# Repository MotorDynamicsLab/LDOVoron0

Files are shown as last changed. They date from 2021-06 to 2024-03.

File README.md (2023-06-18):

# LDO Voron 0.2R1 Kit
This repository contains supplementary information and resources for the LDO Voron 0.2R1 Kit

## Index
- **Firmware**, contains Klipper configuration files custom to the kit.
- **Images**, images from the kit, and wiring guide, etc.
- **STLs**, printable parts and source files. 

## Preset Plates
We have gathered the most commonly parts from the Voron and LDO Repos. We saved them on as 250mm bed plates for your convenience. 

Also 
- [V02 to V02R1 Upgrade Plates]( https://github.com/MotorDynamicsLab/LDOVoron0/tree/v02r1/STLs/Preset_Print_PlatesR1/UpgradeToR1Plates)

## Legacy Versions
Users wishing to access older versions can check out the following branches:
- [V02]( https://github.com/MotorDynamicsLab/LDOVoron0/tree/v02) Branch
- [V01]( https://github.com/MotorDynamicsLab/LDOVoron0/tree/v01) Branch

## License
This repo contains both original and derivative works from the Voron project, 
which is licensed GPLv3. This repo therefore is also licensed under the terms 
of the GNU Public License, verison 3.

GPLv3 License Attributions:

https://github.com/VoronDesign/Voron-0

For more information and support:

https://vorondesign.com

https://discord.gg/voron

https://docs.ldomotors.com

https://www.ldomotion.com

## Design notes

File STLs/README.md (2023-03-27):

## Detachable Spool Holder  
This mod allows the long arm of the spool holder to be completely removed and installed in two orientations (extended or collapsed). The collapsed configuration allows easy storage and transportation.

## DIN Mounts
These are optional low profile clips that allow for your SKR Pico and Raspberry Pi Zero (with USB expander) to be mounted on DIN cleats

## Kirigami
Contains the Stealth Bed Front for mounting a neopixel to the Kirigami bed frame. Also included is a wire breakout mount for cable management.

## Mornsun PSU Cover
A safety shroud that covers up the screw terminals on the Mornsun 24V power supply. Highly recommended to prevents accidental shocks.

## Chain Anchor Skirt  
This part replaces one of the stock skirts. Instead of fastening the Z cable chain to the frame, fasten it to this skirt.

## Nameplate
Clips that can be used to mount the metal LDO kit number to your V0.2 Top hat

## Power Inlet
A slightly modified V0.2 inlet foot that holds the LDO 1.2mm AC inlet more securely.

## RPi Zero USB Expander Mount  
Those that received a Raspberry Pi Zero with the USB expander PCB can use this mount to for installation. Use two M2x10 self tapping screws and the included standoffs for fastening the Expander PCB to the mount. 

## Side Skirt with Chain Anchor
This is a V0.2 Side skirt for those who are upgrading from V0.1 and don't feel like flipping the orientation of the bed cable chain. The skirt contains a mounting point for the bed chain so it can be attached to the skirt instead of the printer frame.

## Slide-in Nut Support  
Supports the slide-in nut by lifting it up and preventing any the nut from sliding around.

## Preset Print Plates
For those who don't feel like figuring out which parts are needed to the LDO kit, we've prepared pre-arranged plates containing all the parts needed to build the kit.

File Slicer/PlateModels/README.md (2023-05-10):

# Slicer Plate Models & Textures
This folder contains models and textures that can be used in SuperSlicer or PrusaSlicer. Open Printer Settings->General->Bed Shape. 
- Under Texture, select "120_ldo_texture.svg"
- Under Model, select "Voron_120_Build_Plate.stl"

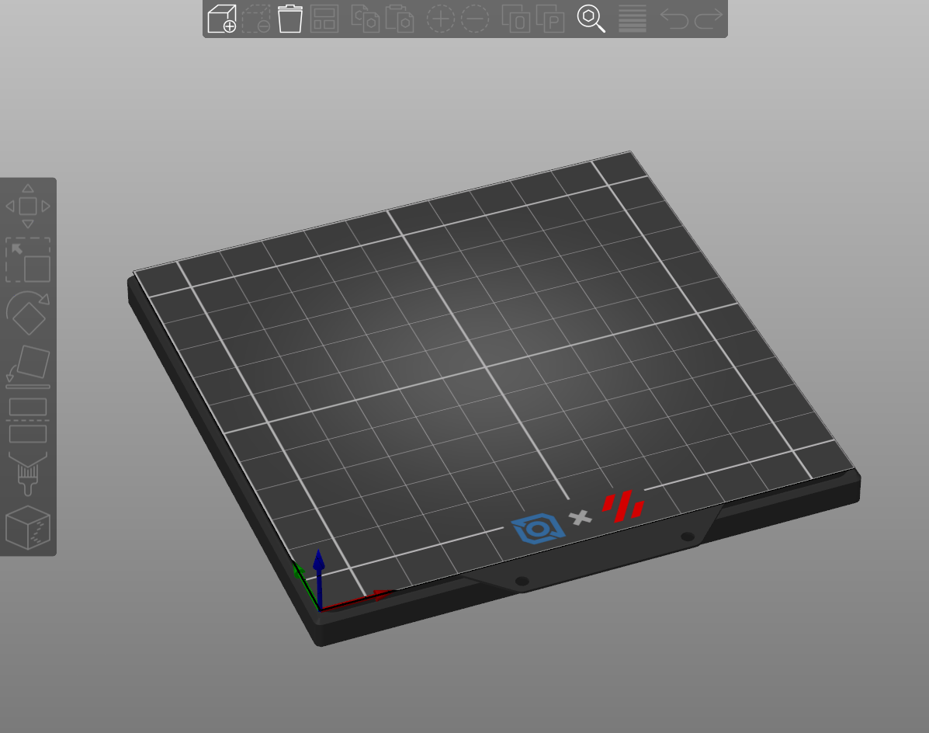
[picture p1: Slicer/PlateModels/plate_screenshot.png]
Screenshot of the LDO custom slicer plate


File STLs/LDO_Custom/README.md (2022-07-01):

# Chain Anchor Skirt
This part replaces one of the stock skirts. Instead of fastening the Z cable chain to the frame, fasten it to this skirt.

# Nameplate Middle Clip
Replaces a normal panel middle clip with a clip that can hold the metal LDO kit number nameplate.

# RPi Zero USB Expander Mount
Those that received a Raspberry Pi Zero with the USB expander PCB can use this mount to for installation. Use two M2x10 self tapping screws and the included standoffs for fastening the Expander PCB to the mount. 

# Slide-in Nut Support
Supports the slide-in nut by lifting it up and preventing any the nut from sliding around.

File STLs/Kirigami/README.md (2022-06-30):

# Kirigami Breakout Mount
This part is designed to work with the Kirigami bed mount mod, it holds 2x WAGO 221-412 terminals, and a 2x2 JST XH Splicer PCB.

# Stealth Bed Front
This is a remix of MapleLeafMakers [Stealth Bed Front Mod](https://github.com/MapleLeafMakers/Stealth_Bed_Front) which incorporates a Neopixel PCB with a JST-XH receptacle. Print the diffuser in clear filament.

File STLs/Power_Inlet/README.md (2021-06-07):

# 1.2mm Power Inlet
This part replaces the standard 1.0mm power inlet from the official [Voron repo](https://github.com/VoronDesign/Voron-0/tree/Voron0.1/STLs). The only difference is this part adapts to 1.2mm AC inlets for a more snug fit.

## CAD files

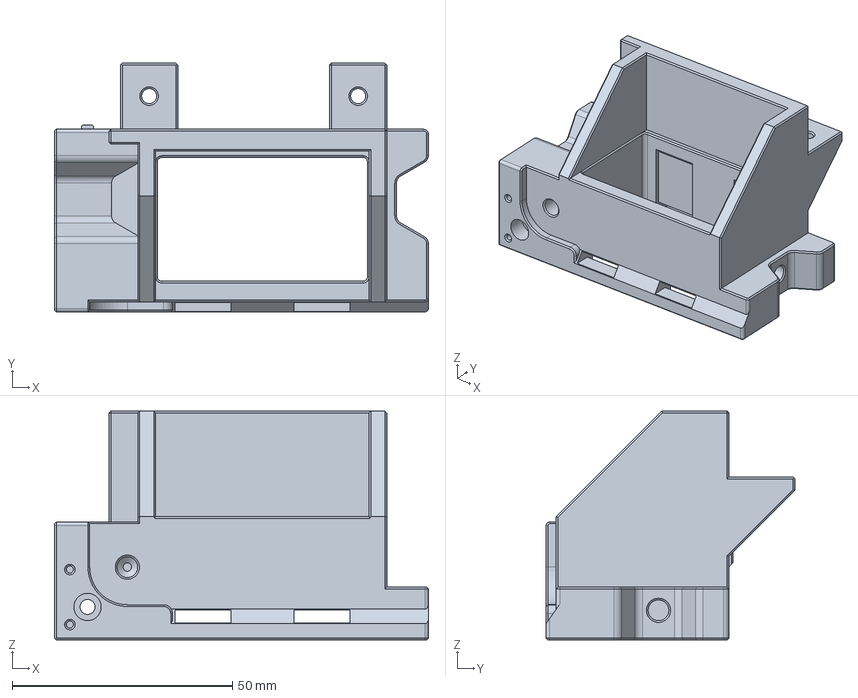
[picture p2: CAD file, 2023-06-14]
STLs/Power_Inlet/V02R1_Mains_Inlet Foot_1_2mm.step
84.9 x 56.5 x 52.0 mm

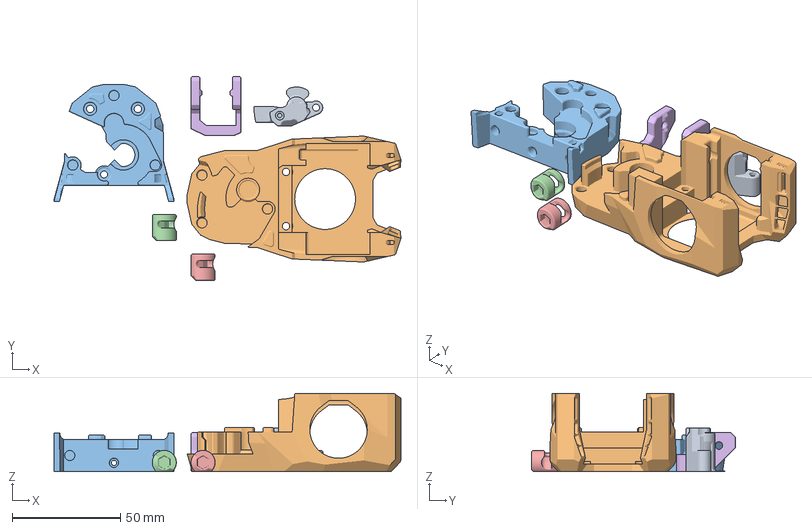
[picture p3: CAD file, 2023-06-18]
STLs/Preset_Print_PlatesR1/UpgradeToR1Plates/LDO_[a]_Main_Toolhead_PlateR1.3mf
160.0 x 93.8 x 36.1 mm
[a]_Guidler_x1.STL
[a]_MiniSB_Cowling_x1.STL
[a]_MiniSB_MidBody_x1.STL
[a]_Idler_Cam_Lock_x2.STL
[a]_Z_Endstop_Mount_x1.STL

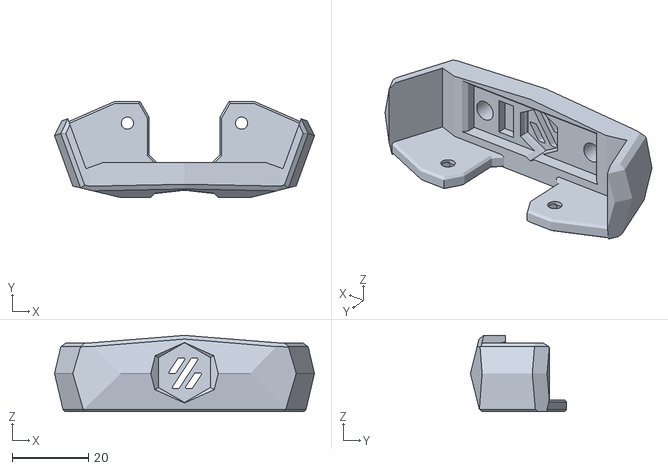
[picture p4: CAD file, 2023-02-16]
STLs/Kirigami/Stealth_Bed_Main_Body.stl
68.2 x 25.2 x 20.0

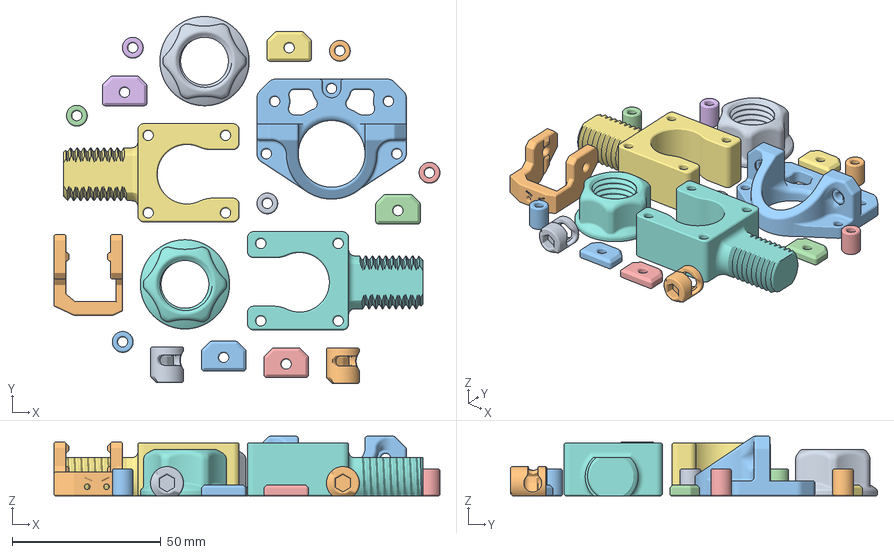
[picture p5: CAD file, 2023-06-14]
STLs/Preset_Print_PlatesR1/LDO_[a]_Main_PlateR1.3mf
129.7 x 123.3 x 20.0 mm
[a]_9mm_Spacer_x6.stl
[a]_A_Drive_Tensioner_x1.stl
[a]_B_Drive_Tensioner_x1.stl
[a]_Idler_Cam_Lock_x2.STL
[a]_Railstops_x5.stl
[a]_Tensioner_Knob_x2.stl
[a]_Z_Endstop_Mount_x1.STL
[a]_Z_Motor_Mount_x1.stl

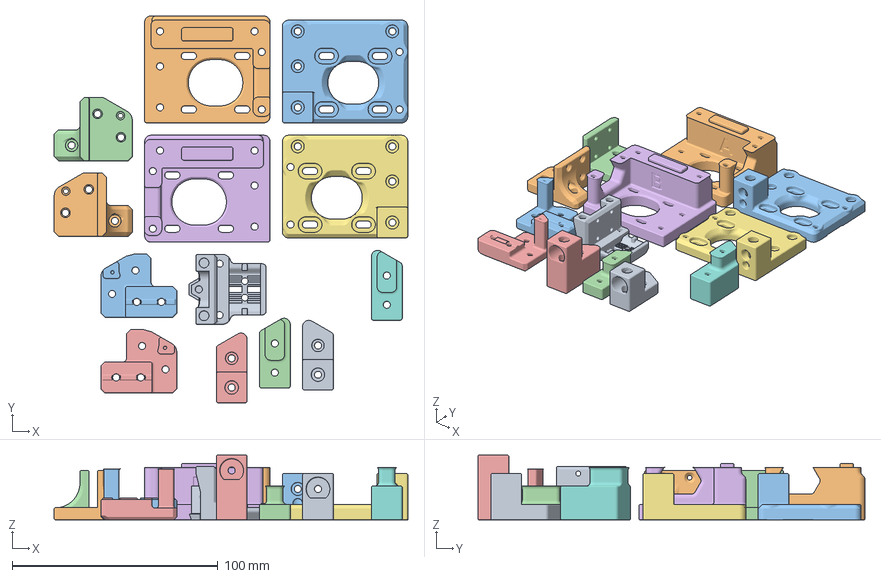
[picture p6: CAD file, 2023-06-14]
STLs/Preset_Print_PlatesR1/LDO_Main_PlateR1.3mf
172.0 x 188.3 x 31.5 mm
X_Carriage_x1.stl
A_Drive_Frame_Lower_x1.stl
A_Drive_Frame_Upper_x1.stl
A_Idler_Lower_x1.stl
A_Idler_Upper_x1.stl
B_Drive_Frame_Lower_x1.stl
B_Drive_Frame_Upper_x1.stl
B_Idler_Lower_x1.stl
B_Idler_Upper_x1.stl
XY_Joint_Left_Lower_x1.stl
XY_Joint_Left_Upper_x1.stl
XY_Joint_Right_Lower_x1.stl
XY_Joint_Right_Upper_x1.stl

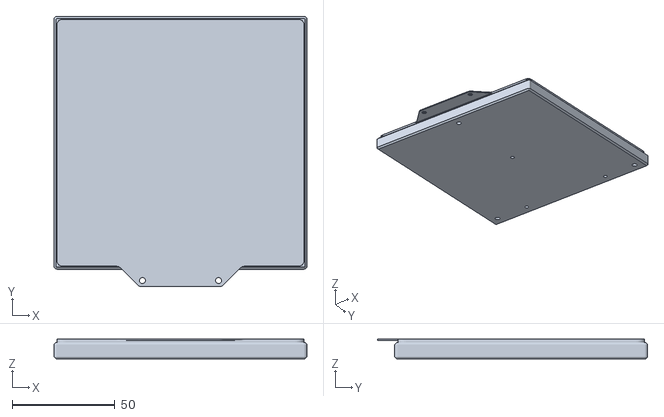
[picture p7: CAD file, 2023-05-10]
Slicer/PlateModels/Voron_120_Build_Plate.stl
123.0 x 131.5 x 9.60

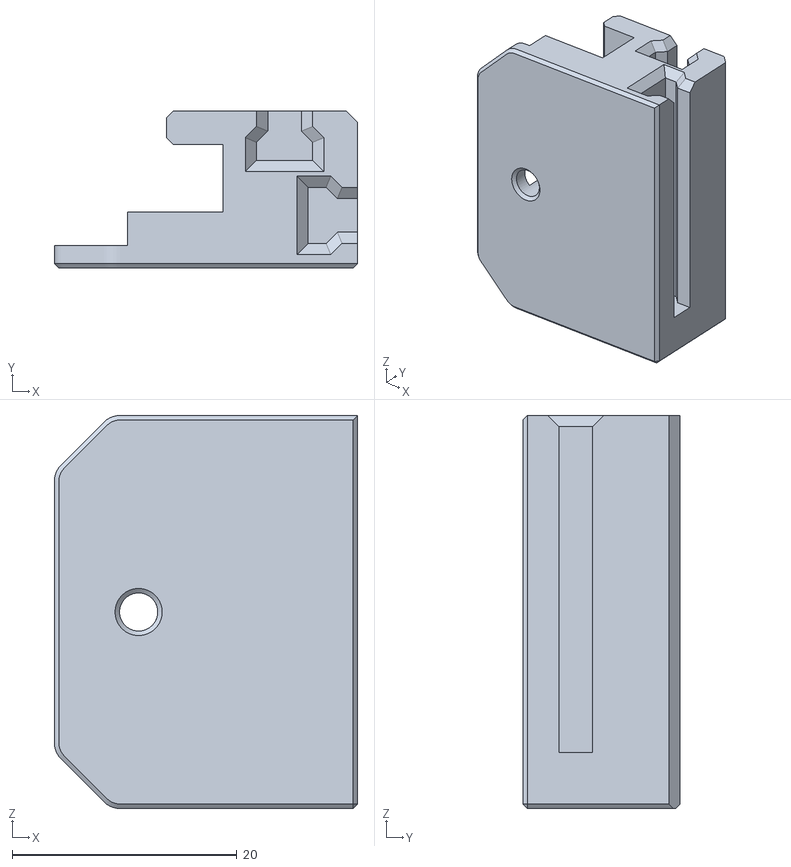
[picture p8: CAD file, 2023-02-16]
STLs/Detachable_Spool_Holder/Spool_Holder_Mount.stl
27.0 x 14.0 x 35.0

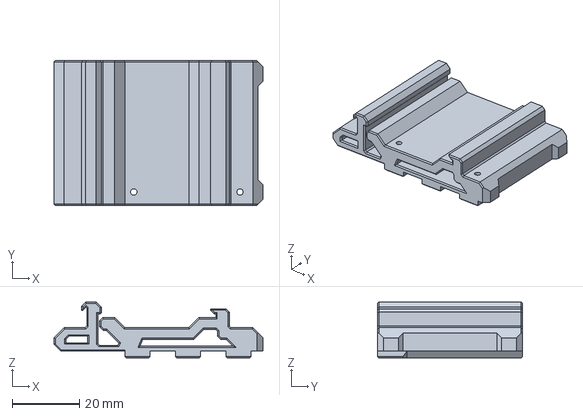
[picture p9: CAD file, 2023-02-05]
STLs/DIN_Mounts/Pi Expansion Clips.step
62.0 x 43.0 x 16.6 mm

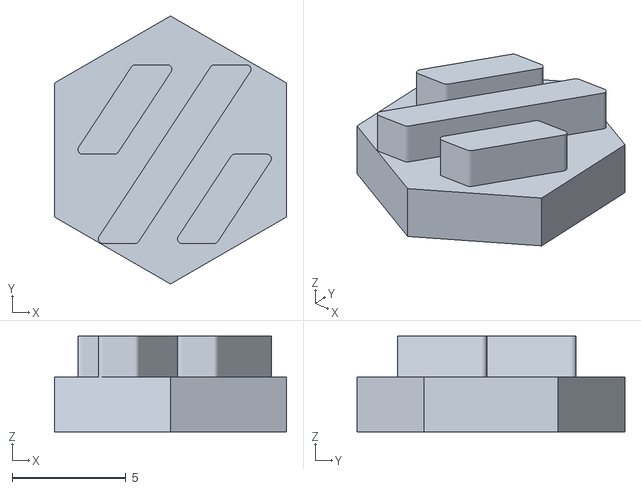
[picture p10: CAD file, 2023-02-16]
STLs/Kirigami/[c]_Stealth_Bed_Diffuser.stl
10.2 x 11.8 x 4.20

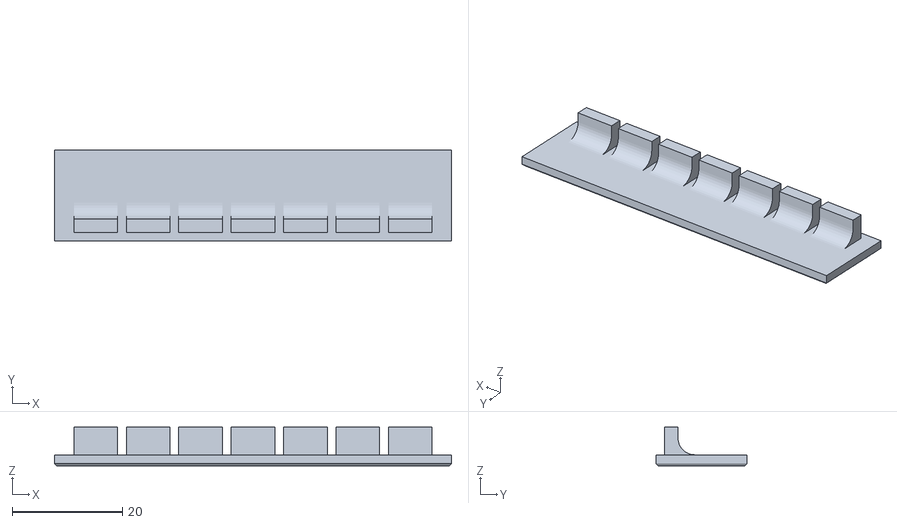
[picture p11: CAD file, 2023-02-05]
STLs/Mornsun_PSU_Cover/Mornsun_PSU_Cover.stl
72.0 x 16.5 x 7.00

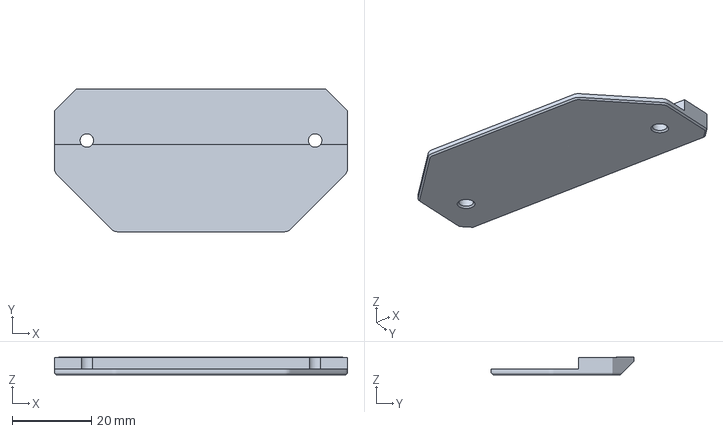
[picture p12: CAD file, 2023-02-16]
STLs/Name_Plate/Name_Plate_Top_Logo_Multi.3mf
73.8 x 35.9 x 4.42 mm

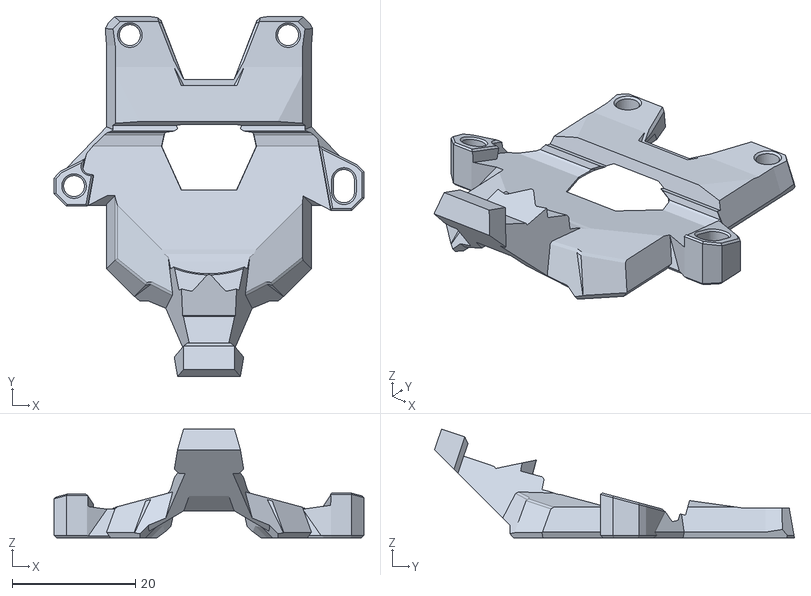
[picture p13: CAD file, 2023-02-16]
STLs/Picobilical_Toolhead/Picobilical_Strain_Relief.stl
50.3 x 58.5 x 17.7

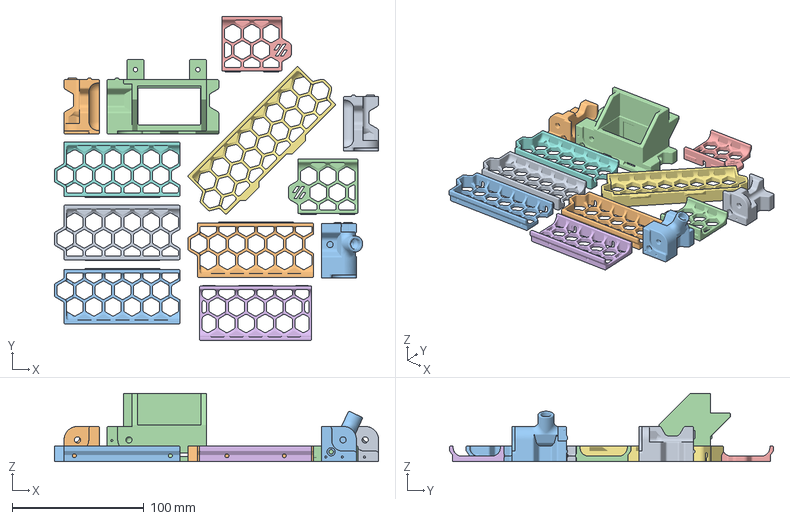
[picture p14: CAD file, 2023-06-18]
STLs/Preset_Print_PlatesR1/UpgradeToR1Plates/LDO_Skirts_PlateR1.3mf
246.6 x 246.3 x 52.0 mm
Foot_Front_Left_x1.STL
Foot_Front_Right_x1.STL
Foot_Rear_Right_FRS_x1.STL
Front_Skirt_A_x1.STL
Front_Skirt_B_x1.STL
Headless_Skirt_Insert.STL
Rear_Skirt_x1.STL
Side_Skirt_Mirror_x2.stl
Side_Skirt_x2.STL
V02R1_Mains_Inlet Foot_1_2mm.stl

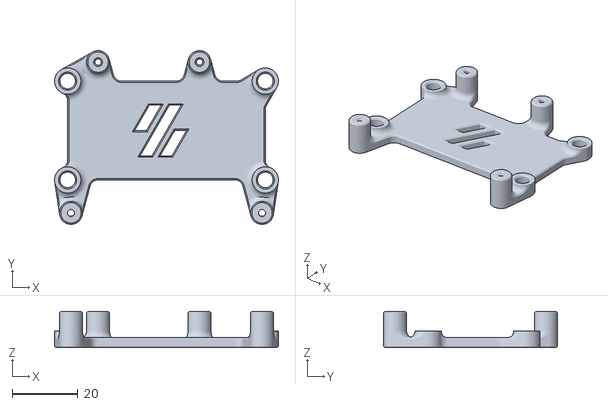
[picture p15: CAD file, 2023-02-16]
STLs/RPi_Zero_USB_Expander_Mount/RPi_Zero_USB_Expander_Mount.stl
68.0 x 52.8 x 11.0

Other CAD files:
STLs/Preset_Print_PlatesR1/LDO_[c]_Mods_KirigamiR1.3mf
STLs/Detachable_Spool_Holder/Spool_Holder.stl
STLs/DIN_Mounts/SKR Pico Mount_x2.step
STLs/Kirigami/Kirigami_LDO_Breakout_Mount.stl
STLs/DIN_Mounts/DIN Screw Cleat_x2.step
STLs/DIN_Mounts/DIN Screw Cleat_x2.stl
STLs/DIN_Mounts/Pi Expansion Clips.stl
STLs/DIN_Mounts/SKR Pico Mount_x2.stl
STLs/Detachable_Spool_Holder/V0 Detachable Spool Holder.f3d
STLs/Kirigami/Kirigami LDO Breakout Mount.f3d
STLs/Kirigami/Stealth Bed Front.f3d
STLs/Mornsun_PSU_Cover/Mornsun PSU Cover.f3d
STLs/Name_Plate/Name_Plate.stl
STLs/Name_Plate/Name_Plate_Top.stl
STLs/Name_Plate/Name_Plate_Top_Logos.stl
STLs/Picobilical_Toolhead/Picobilical Toolhead Mount V02.step
STLs/Picobilical_Toolhead/Picobilical_Strain_Relief_Extender_x2.stl
STLs/Picobilical_Toolhead/Picobilical_Strain_Relief_Spacer_A.stl
STLs/Picobilical_Toolhead/Picobilical_Strain_Relief_Spacer_B.stl
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

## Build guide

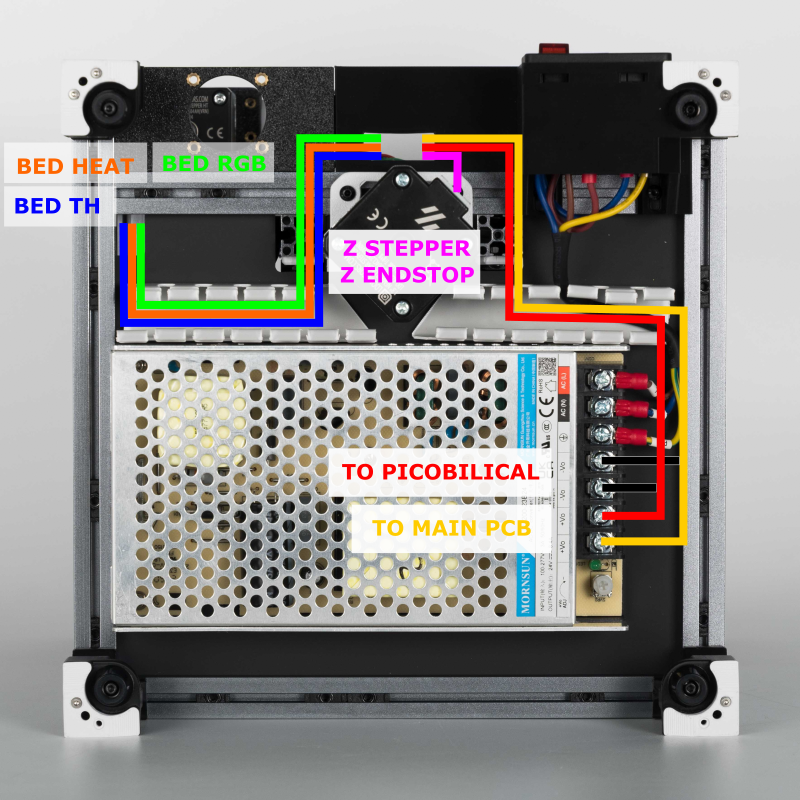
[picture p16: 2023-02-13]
Images/WiringGuide/v02/s04_mapping.png

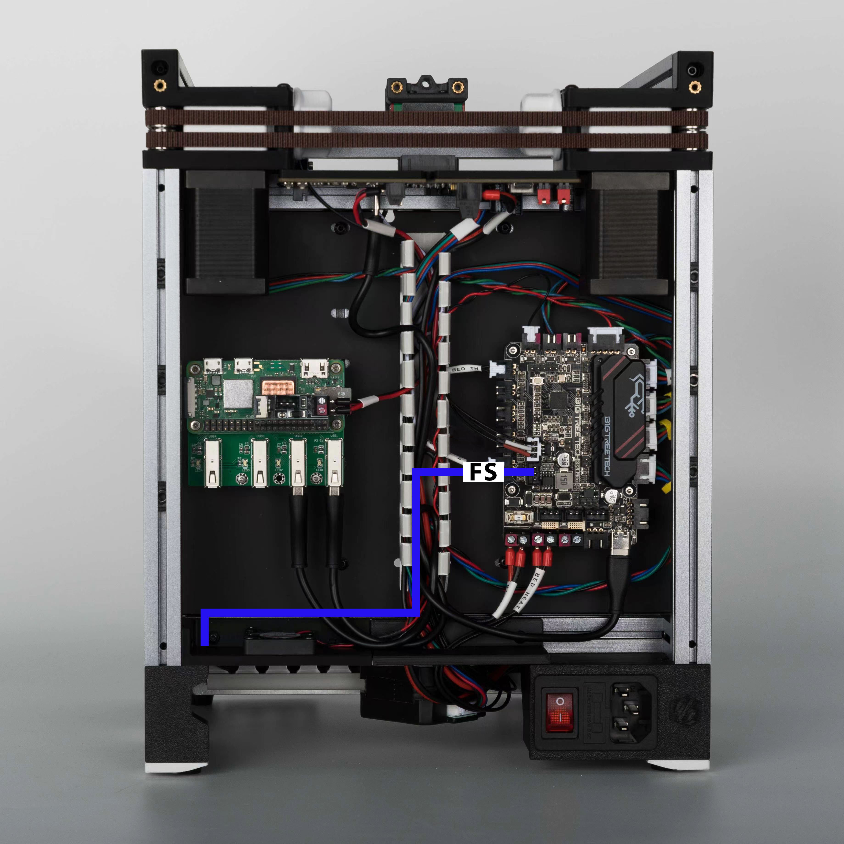
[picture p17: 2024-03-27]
Images/WiringGuide/S1/s14_mapping.jpg

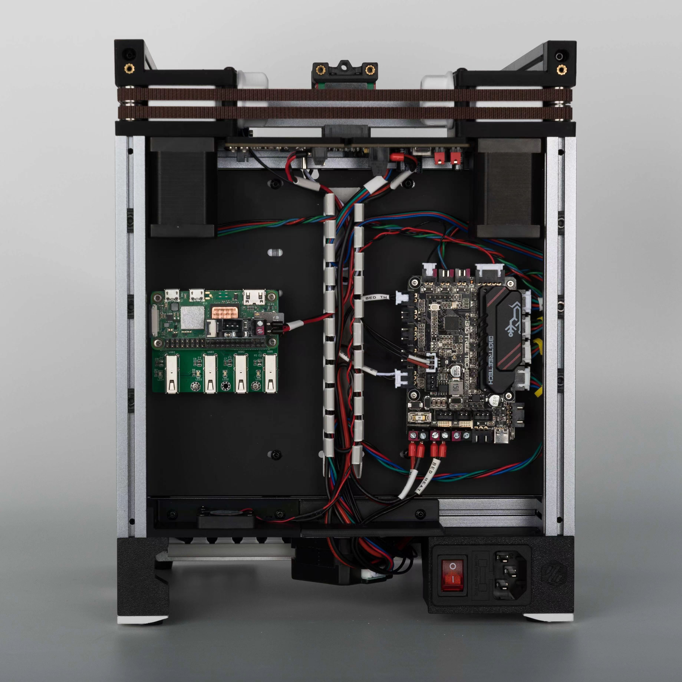
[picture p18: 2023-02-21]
Images/WiringGuide/v02/s11_pcb_fan.jpg

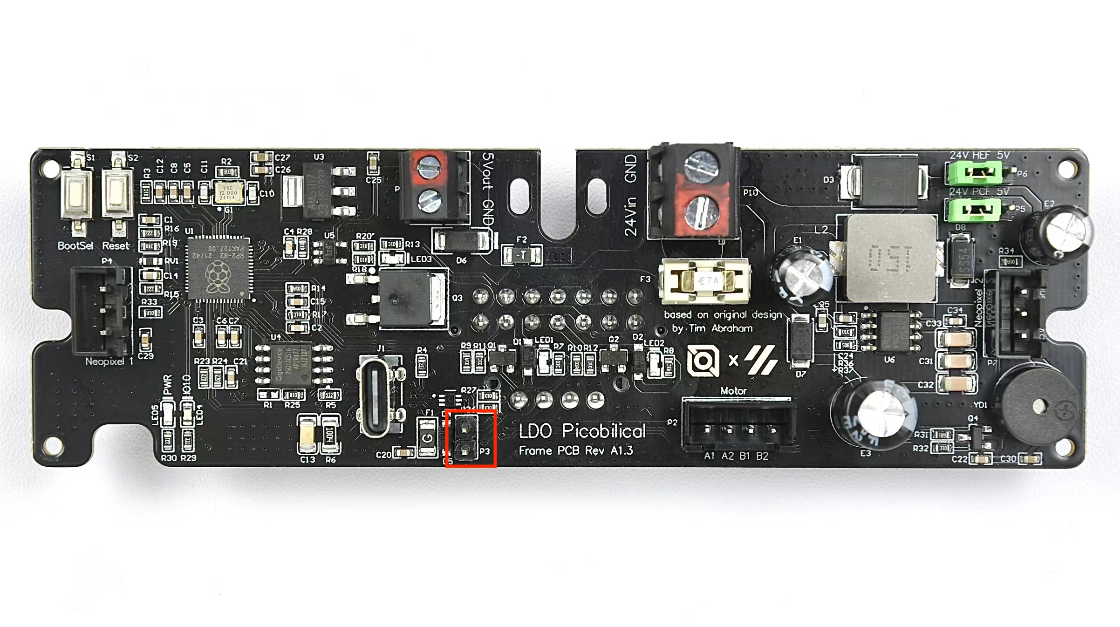
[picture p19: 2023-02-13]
Images/WiringGuide/v02/picobilical_hef_24v_usb_jumper_labelled.jpg

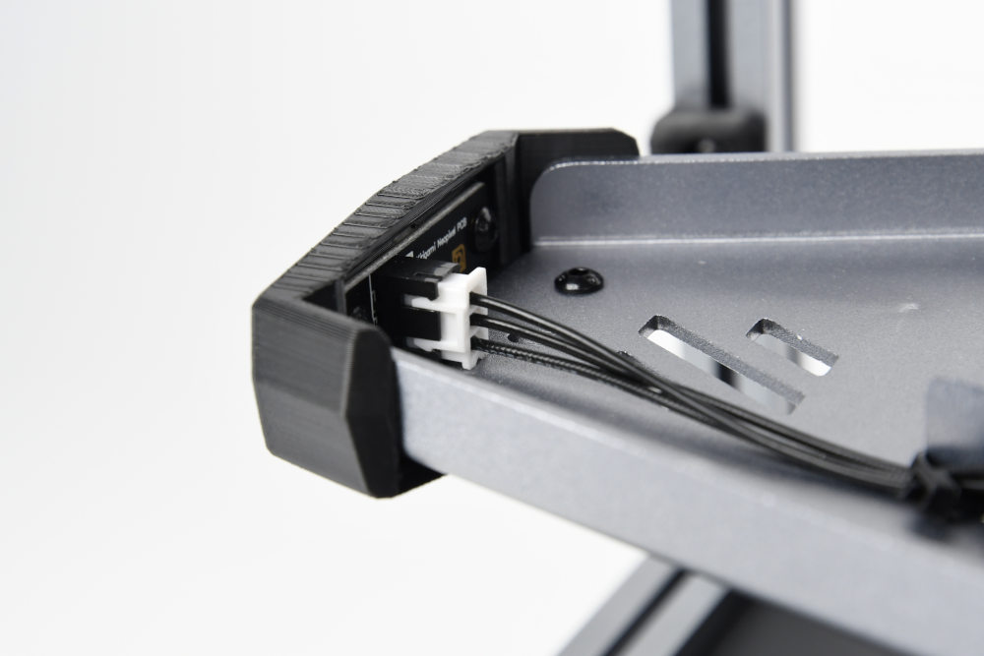
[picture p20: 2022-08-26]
Images/Kirigami/kirigami_neopixel_cable_installed.JPG

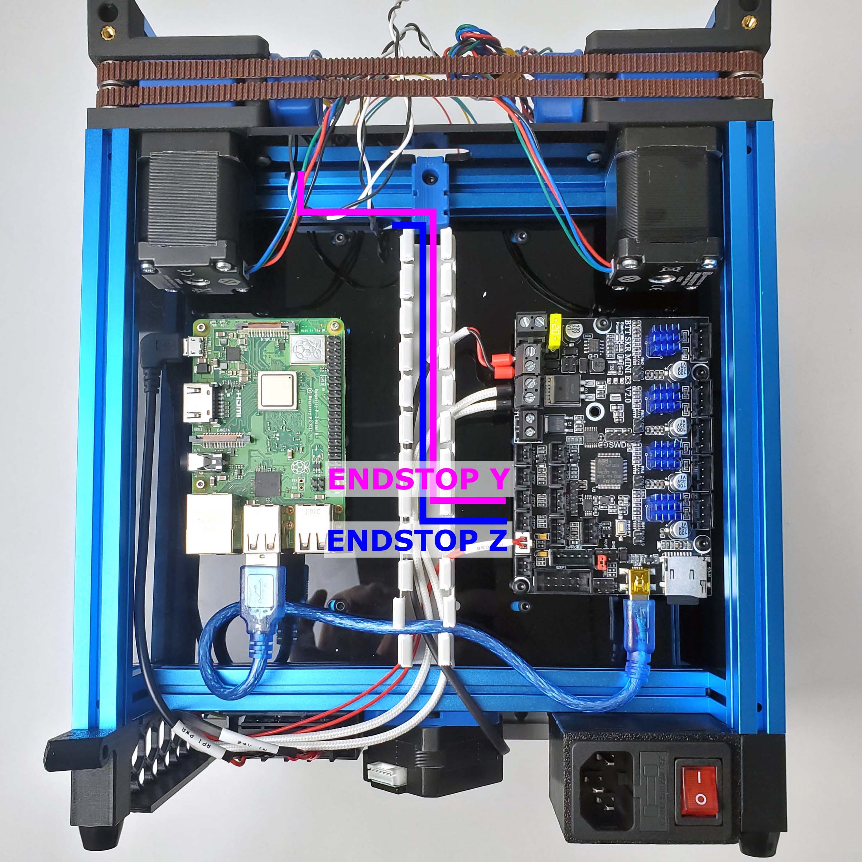
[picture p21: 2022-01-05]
Images/WiringGuide/elec2_layout.jpg

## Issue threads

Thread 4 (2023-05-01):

Picobilical toolhead spacer missing from Preset_Print_Plates

slashbeast, 2023-05-01:
The printed parts guide at https://docs.ldomotors.com/voron/voron02/printed_part_guide_rev_a mention toolhead spacer for Picobilical but the part seems to be missing in preset print plates, is it intentional?

camerony, 2023-08-29:
This was fixed.  Thanks

Closed 2023-08-29.

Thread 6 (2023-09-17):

Documentation docs.ldomotors.com/en/voron/voron02/build-faqv02

JassMan23, 2023-09-17:
The above document says:
"PAGE 143 Use M3 lock nuts with the flat side up rather the the M3 hex nut and washer. We recommend
using an M3x30 or M3x35 screw for the Kirigami bed instead of the M3x40"

However it is virtually impossible to to install a lock nut backwards without stripping the nut or the screw since the nylon lock can not be guaranteed to cut a thread which is a continuation of the actual nut thread. Because of its resilience, the thread in the nylon recovers its smoothness before you are able to reverse it, if you thread it the normal way first.

A better solution is to use 2 hex (jam)nuts so the second locks against the first.
Or providing something like this: 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

camerony, 2023-09-28:
Thanks for the feedback.  We will consider that.

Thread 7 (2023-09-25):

Power inlet needs to be resized

MrJohnson, 2023-09-25:
From the 0.2 R1 release notes:

"Skirts

We fixed the issue where 34mm Z motors didnt fit in the machine with the bottom panel installed, this involved increasing the height of the skirts/feet by 2mm
We added a simple filament runout sensor to the rear right foot"

The LDO-provided power inlet stl is now a different size than the official release and causes the printer to rock.

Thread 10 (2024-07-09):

Wrong GPIO listed for Filament Sensor 1

xanderphillips, 2024-07-09:
File has:
switch_pin: umb:gpio6

But if the wiring was done per the documentation to the E Stop on the SKR Pico board, the entry should be:
switch_pin: !gpio16

Found via the bigtreetech github for the SKR Pico board.

cneshi, 2024-07-09:
Both pins are already listed in the config for you to choose because both the SKR Pico and Picobilical have filament sensor ports. Please see line 379 - 389 in printer.cfg

Closed 2024-07-09.

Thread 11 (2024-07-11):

homing problem with z when issuing

xanderphillips, 2024-07-11:
To repro:
issue G28 X or G28 Y repeatedly without issuing a G28 Z or a home all command.

Slipperyclock, 2025-06-09:
I have had the same issue with mine.  Newly built LDO V0.2 S1, ran fine for a little while then all of a sudden this problem came up.  I had to remove the "Z20" from line 492, https://github.com/MotorDynamicsLab/LDOVoron0/blob/4c543a41f25372adbd4c650e5aab1d722c46461a/Firmware/printer.cfg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.

I am surprised no one else is having this issue its almost a year.

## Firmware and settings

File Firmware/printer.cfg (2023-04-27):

## LDO V0.2 Printer Configuration
## NOTE: The order of the [include] are IMPORTANT


#####################################################################
#   User Interface Software
#####################################################################
## Uncomment depending on your software choice either Fluidd or Mainsail
# [include fluidd.cfg]
# [include mainsail.cfg]

[mcu]
#####################################################################
# Obtain definition by "ls -l /dev/serial/by-id/"
#####################################################################
serial: /dev/serial/by-id/{REPLACE WITH YOUR SERIAL}
restart_method: command
##--------------------------------------------------------------------

[mcu umb]
##  Obtain definition by "ls -l /dev/serial/by-id/" then unplug to verify
##--------------------------------------------------------------------
serial: /dev/serial/by-id/{REPLACE WITH YOUR SERIAL}
restart_method: command
##--------------------------------------------------------------------


#####################################################################
#   Main Controller Board
#####################################################################
# This file contains common pin mappings for the BIGTREETECH SKR Pico V1.0
# To use this config, the firmware should be compiled for the RP2040 with
# USB communication.

# The "make flash" command does not work on the SKR Pico V1.0. Instead,
# after running "make", copy the generated "out/klipper.uf2" file
# to the mass storage device in RP2040 boot mode

## Voron Design VORON 0.1 SKR Pico V1.0 config

## *** THINGS TO CHANGE/CHECK: ***
## MCU path                                                                     [mcu] section
## Z and Extruder motor currents                                                [tmc2209 stepper_*] sections. Uncomment the stepper motor you have
## Full steps per rotation for Extruder                                         [extruder] section
## Thermistor types                                                             [extruder] and [heater_bed] sections - See https://www.klipper3d.org/Config_Reference.html#common-thermistors for common thermistor types
## Extruder motor currents                                                      [extruder] section
## PID tune                                                                     [extruder] and [heater_bed] sections
## Fine tune E steps                                                            [extruder] section
## For more info                                                                check https://docs.vorondesign.com/build/startup/#v0

[printer]
kinematics: corexy
max_velocity: 200
max_accel: 2000
max_z_velocity: 15
max_z_accel: 45
square_corner_velocity: 6.0

#####################################################################
#      X/Y Stepper Settings
#####################################################################

[stepper_x]
step_pin: gpio11
## Refer to https://docs.vorondesign.com/build/startup/#v0
dir_pin: gpio10                                                     # Check motor direction in link above. If inverted, add a ! before gpio10
enable_pin: !gpio12
rotation_distance: 40
microsteps: 32
full_steps_per_rotation: 200                                        # Set to 400 for 0.9° degree stepper motor, 200 is for 1.8° stepper motors
endstop_pin: ^gpio4                                                 # LDO Picobilical overrides this setting 
position_endstop: 120
position_max: 120
homing_speed: 50                                                    # Can be increased after initial setup, Max 100
homing_retract_dist: 5
homing_positive_dir: true

[tmc2209 stepper_x]
uart_pin: gpio9
tx_pin: gpio8
uart_address: 0
interpolate: False
run_current: 0.5
sense_resistor: 0.110
stealthchop_threshold: 0                                            # Set to 999999 to turn stealthchop on, and 0 to use spreadcycle

[stepper_y]
step_pin: gpio6
## Refer to https://docs.vorondesign.com/build/startup/#v0
dir_pin: gpio5                                                      # Check motor direction in link above. If inverted, add a ! before gpio5
enable_pin: !gpio7
rotation_distance: 40
microsteps: 32
full_steps_per_rotation: 200                                        # Set to 400 for 0.9° degree stepper motor, 200 is for 1.8° stepper motors
endstop_pin: ^gpio3
position_endstop: 120
position_max: 120
homing_speed: 50                                                    # Can be increased after initial setup, Max 100
homing_retract_dist: 5
homing_positive_dir: true

[tmc2209 stepper_y]
uart_pin: gpio9
tx_pin: gpio8
uart_address: 2
interpolate: False
run_current: 0.5
sense_resistor: 0.110
stealthchop_threshold: 0                                            # Set to 999999 to turn stealthchop on, and 0 to use spreadcycle

#####################################################################
#   Z Stepper Settings
#####################################################################

[stepper_z]
step_pin: gpio19
dir_pin: !gpio28                                                    # Remove the ! before gpio28 if motor direction is inverted.
enable_pin: !gpio2
rotation_distance: 8                                                # For T8x8 integrated lead screw
microsteps: 32
endstop_pin: ^gpio25
position_endstop: 120                                              # Default endstp position on the bottom for v0.2
position_max: 120
position_min: -1.5
homing_speed: 10
second_homing_speed: 3.0
homing_retract_dist: 3.0

[tmc2209 stepper_z]
uart_pin: gpio9
tx_pin: gpio8
uart_address: 1
interpolate: False
## For LDO-42STH25-1004CL200E 1.0A
run_current: 0.37
sense_resistor: 0.110
stealthchop_threshold: 0                                            # Set to 999999 to turn stealthchop on, and 0 to use spreadcycle

#####################################################################
#   Extruder
#####################################################################

[extruder]
step_pin: gpio14
dir_pin: gpio13                                                     # Add ! if moving opposite direction
enable_pin: !gpio15
full_steps_per_rotation: 200                                       # Set to 200 for LDO 1.8° stepper motor, and set to 400 for OMC(StepperOnline) 0.9° stepper motor
rotation_distance: 22.23                                            # See calibrating rotation_distance on extruders doc
gear_ratio: 50:10                                                   # For Mini Afterburner
microsteps: 32
nozzle_diameter: 0.400
filament_diameter: 1.750
heater_pin: gpio23                                                  # LDO Picobilical overrides this setting 
## Check what thermistor type you have. See https://www.klipper3d.org/Config_Reference.html#common-thermistors for common thermistor types.
## Use "Generic 3950" for NTC 100k 3950 thermistors
sensor_type: ATC Semitec 104NT-4-R025H42G                           # LDO Picobilical overrides this setting
sensor_pin: gpio27                                                  # LDO Picobilical overrides this setting
control: pid                                                        # Do PID calibration after initial checks
pid_Kp: 28.182
pid_Ki: 1.978
pid_Kd: 100.397
min_temp: 0
max_temp: 270
min_extrude_temp: 170
max_extrude_only_distance: 150
max_extrude_cross_section: 0.8
pressure_advance: 0.0                                               # See tuning pressure advance doc
pressure_advance_smooth_time: 0.040

[tmc2209 extruder]
uart_pin: gpio9
tx_pin: gpio8
uart_address: 3
interpolate: False
## For LDO LDO 36STH17-1004AHG 1A 1.8° 
#run_current: 0.3 # for LDO 36STH17-1004AHG
## For LDO LDO 36STH20-1004AHG 1A 1.8° 
run_current: 0.6 # for LDO 36STH20-1004AHG
sense_resistor: 0.110
stealthchop_threshold: 0                                            # Set to 0 for spreadcycle, avoid using stealthchop on extruder

#####################################################################
#   Bed Heater
#####################################################################

[heater_bed]
heater_pin: gpio21
## Check what thermistor type you have. See https://www.klipper3d.org/Config_Reference.html#common-thermistors for common thermistor types.
## Use "Generic 3950" for Keenovo heaters
sensor_type: ATC Semitec 104NT-4-R025H42G 
sensor_pin: gpio26
smooth_time: 3.0
#max_power: 0.6                                                     # Only needed for 100w pads
min_temp: 0
max_temp: 120
control: pid                                                        # Do PID calibration after initial checks
pid_kp: 68.453
pid_ki: 2.749
pid_kd: 426.122

#####################################################################
# Fan Control
#####################################################################
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

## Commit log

2021-06-07 modify README.md, add 1.2mm Power Inlet part
    [Power_Inlet_1.2mm.f3d, Power_Inlet_1.2mm.stl]
2022-01-05 add source files for wiring guide images and diagrams
2022-01-05 swap labels for motor A and B in elec4_layout
2022-01-06 add strain relief spacers that match motor heights specific to LDO
    [Strain_Relief_Spacer_36STH17.f3d, Strain_Relief_Spacer_36STH17_x2.stl, Strain_Relief_Spacer_36STH20.f3d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]
2022-01-06 add README.md for new spacer files
2022-01-06 fix incorrect height of Strain_Relief_Spacer_36STH20 (17 to 16mm)
    [Strain_Relief_Spacer_36STH20.f3d, Strain_Relief_Spacer_36STH20_x2.stl]
2022-01-06 Update README.md
    fix image links in /STLs/Spacers/README.md
2022-01-06 Fix syntax error in STLs/Spacers/README.md
2022-03-01 add Chain Anchor Skirt
    [Chain Anchor Skirt.f3d, Chain_Anchor_Skirt.stl]
2022-05-11 add Kirigami LDO Breakout Mount
    [Kirigami LDO Breakout Mount.f3d, Kirigami_LDO_Breakout_Mount.stl]
2022-05-27 add Nameplate Middle Clip
    [Nameplate Middle Clip.f3d, Nameplate_Middle_Clip.stl]
2022-05-27 Fix orientation of Nameplate_Middle_Clip.stl
    [Nameplate_Middle_Clip.stl]
2022-06-02 add extra spacing in Nameplate Middle Clip
    [Nameplate Middle Clip.f3d, Nameplate_Middle_Clip.stl]
2022-06-20 add RPi Zero USB Expander Mount
    [RPi Zero USB Expander Mount.f3d, RPi_Zero_USB_Expander_Mount.stl]
2022-06-30 Move Kirigami LDO Breakout Mount to its own directory
    [Kirigami LDO Breakout Mount.f3d, Kirigami_LDO_Breakout_Mount.stl]
2022-06-30 add remix of Stealth Bed Front mod (https://github.com/MapleLeafMakers/Stealth_Bed_Front)
    [Stealth Bed Front.f3d, Stealth_Bed_Main_Body.stl, [c]_Stealth_Bed_Diffuser.stl]
2022-07-01 add Slide-in Nut Support
    [Slide-in Nut Support.f3d, Slide_In_Nut_Support.stl]
2022-08-26 add kirigami wiring photos
2022-09-01 Add images for V0-S1 wiring guide
2022-09-01 Add additional photos for S1 wiring guide
2022-09-01 rename photos from v0-s1 wiring guide
2022-09-01 Add missing gnd wire in s04 diagram
2022-10-27 add detachable spool holder mod
    [Spool_Holder.stl, Spool_Holder_Mount.stl, V0 Detachable Spool Holder.f3d]
2022-11-21 add bottom fan panel mod
    [Electronics Bay Fan Panel.f3d, Fan Panel Left.stl, Fan Panel Right.stl]
2022-11-21 rename directory for Bottom Fan Panel
    [Electronics Bay Fan Panel.f3d, Fan Panel Left.stl, Fan Panel Right.stl]
2022-11-23 add Corner_Inlet_1.2mm
    [Corner_Inlet_1.2mm.f3d, Corner_Inlet_1.2mm.stl]
2022-12-29 Mornsun PSU Cover
    [Mornsun PSU Cover.f3d, Mornsun PSU Cover.stl]
2023-02-05 v02 stuff
    Name_Plate
    Clean-Up
    PowerInlet
    Updates
    Delete Name_Plate.zip
    Updates
    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
    [Chain Anchor Skirt.f3d, Chain_Anchor_Skirt.stl, Corner_Inlet_1.2mm.f3d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]
2023-02-05 V02 Plates
    [DIN Screw Cleat_x2.3mf, DIN Screw Cleat_x2.stl, LDO_V02_Plate.3mf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]
2023-02-05 Add Plates
    [LDO_Electronics_Tools_Inlet_Plate.3mf, LDO_Main_Plate.3mf, LDO_Mods_Kirigami.3mf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]
2023-02-13 update skr_pico_prep.JPG and picobilical_prep.JPG for V0.2 wiring guide
2023-02-13 update wiring mapping images for V0.2
2023-02-13 add picobilical toolhead images
2023-02-13 add skr pico and picobilical jumper diagrams
2023-02-14 Remove printer profiles
    [LDO_Custom_Plate.3mf, LDO_Electronics_Tools_Inlet_Plate.3mf, LDO_Main_Plate.3mf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]
2023-02-16 Convert 3mf to STL for individual models
    [DIN Screw Cleat_x2.3mf, DIN Screw Cleat_x2.stl, Kirigami_LDO_Breakout_Mount.3mf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]
2023-02-21 update 0.2 wiring guide images with Y endstop cables removed
2023-02-23 Changed default z endstop to bottom. Commented out safe_z_home
    [printer.cfg, skr-pico-v1.0.cfg]
2023-03-07 remove duplicate load_filament & unload_filament macros in client_macros.cfg
    [client_macros.cfg]
2023-03-27 update STL/README.md with descriptions for all the mods and parts
2023-04-27 Consolidate configs into printer.cfg
    [client_macros.cfg, ldo-picobilical.cfg, printer.cfg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]
2023-05-10 add custom LDO slicer plate models and textures
    [Voron_120_Build_Plate.stl]
2023-05-22 Update LDO_Mods_Kirigami.3mf
    V0.2 Parts for Kirigami (not all may be required)
    [LDO_Mods_Kirigami.3mf]
2023-05-23 Added Picobilical Plate
    [LDO_Custom_Plate.3mf, LDO_Picobilical_Plate.3mf]
2023-06-14 Update Branch to V02R1
    [Mains_Inlet Foot_1.2mm.step, V02R1_Mains_Inlet Foot_1_2mm.step, V02R1_Mains_Inlet Foot_1_2mm.stl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]
2023-06-14 Update Preset Plates for R1
    [LDO_Custom_Plate.3mf, LDO_Custom_PlateR1.3mf, LDO_Electronics_Tools_Inlet_Plate.3mf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]
2023-06-18 Upgrade Plates to R1
    [LDO_Skirts_PlateR1.3mf, LDO_[a]_Main_Toolhead_PlateR1.3mf]
2023-07-11 add new kirigami images with updated (stealth) printed parts
